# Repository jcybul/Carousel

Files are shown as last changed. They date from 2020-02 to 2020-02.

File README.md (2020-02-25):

# Carousel

The Carousel Irrigation System at the Southern Arava R&D is an agricultural research system used to measure the effects of different water salinities on plants.

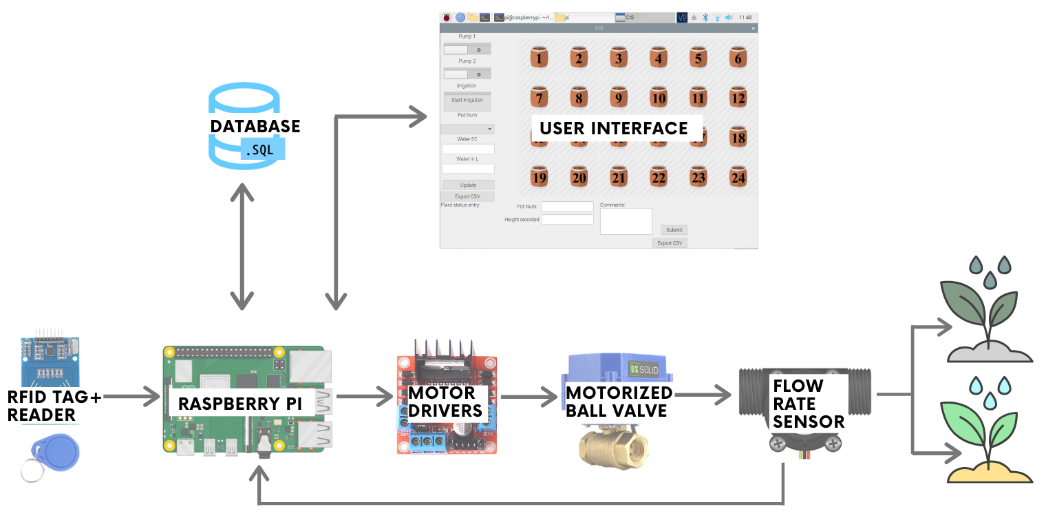
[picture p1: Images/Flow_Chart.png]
Flow chart


The system is divided into three main components:
   1. Hardware 
   2. Database 
   3. User-interface 
   
# HARDWARE

This project is meant to create a supplementary automatic irrigation system to the existing carousel, using the spinning capabilities it already has. For this project we will be using a Raspberry Pi 4 with Raspbian as the operating system. The hardware components required are the following: 

   1 Raspberry pi 4 (https://www.raspberrypi.org/products/raspberry-pi-4-model-b/)
   2  Electronic ball valves (https://www.amazon.com/gp/product/B06XRJF4JG/ref=ppx_yo_dt_b_search_asin_title?ie=UTF8&psc=1)
   2 Flow rate sensors (https://www.amazon.com/gp/product/B00VKAT9VA/ref=ppx_yo_dt_b_search_asin_title?ie=UTF8&psc=1)
   1 L298N motor driver (https://cdn.instructables.com/ORIG/FCN/YABW/IHNTEND4/FCNYABWIHNTEND4.pdf)
   1 RFID scanner (https://www.amazon.com/gp/product/B076HSDF2Y/ref=ppx_yo_dt_b_search_asin_title?ie=UTF8&psc=1)
   24 RFID tags (https://www.amazon.com/gp/product/B076HSDF2Y/ref=ppx_yo_dt_b_search_asin_title?ie=UTF8&psc=1)

Aside from that, a soldering board extension and a soldering iron is recommended for organization

The wiring of the system can be seen in the pictures below:

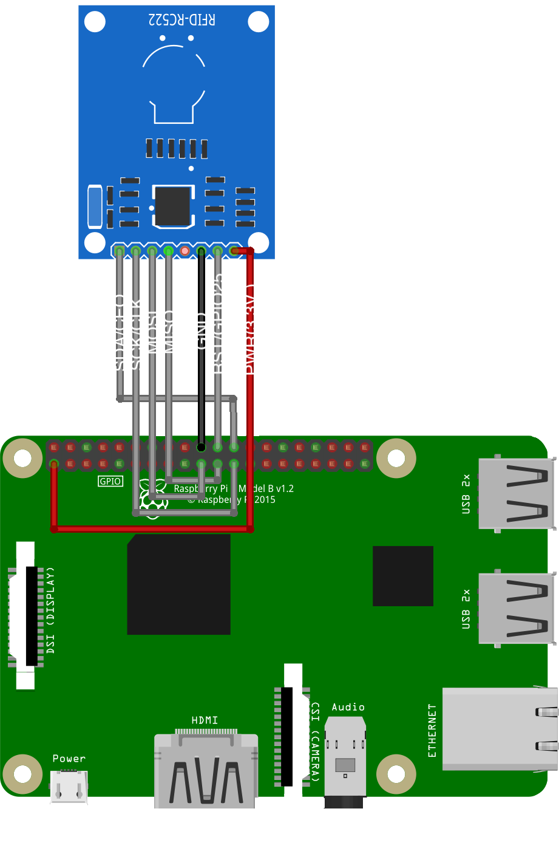
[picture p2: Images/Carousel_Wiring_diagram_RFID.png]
Wiring Diagram of the RFID scanner

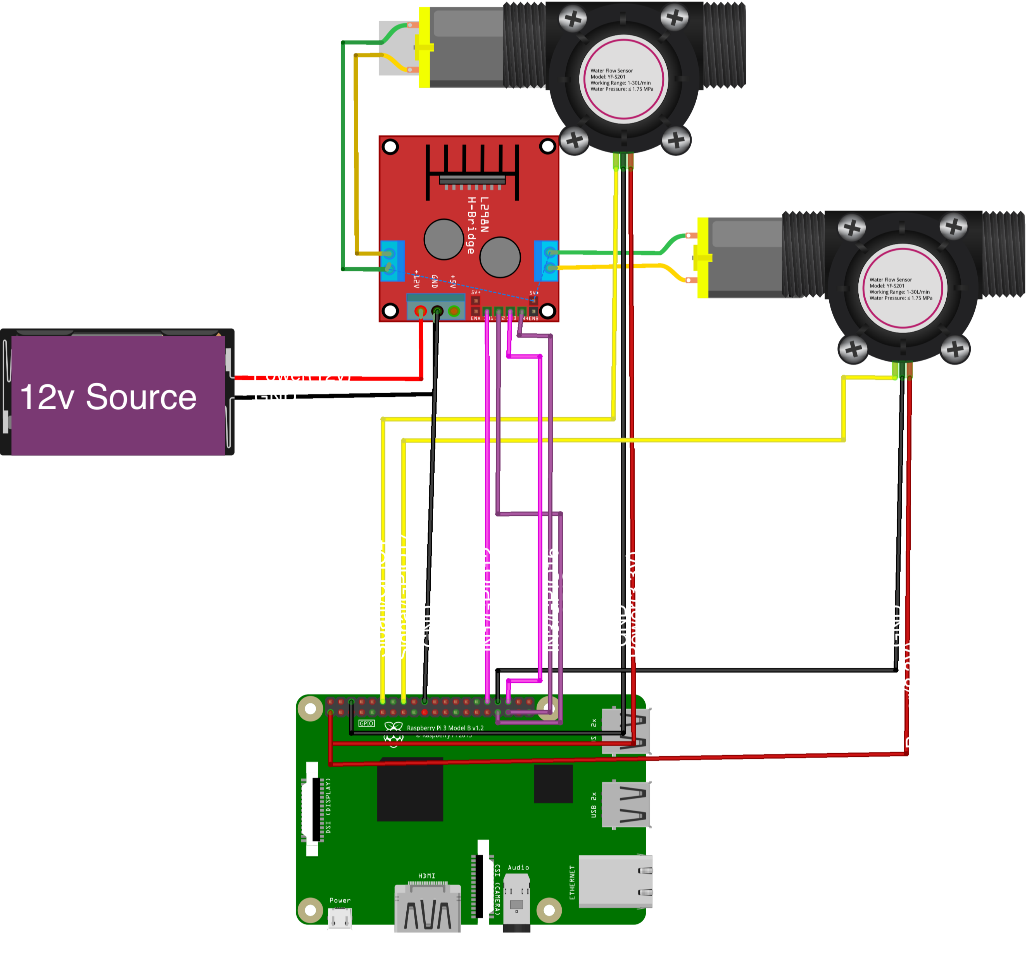
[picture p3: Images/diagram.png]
Wiring Diagram of the Flowrate sensors and ball valves
 

[Refer to the fritzing files for more detailed information]( /Fritzing_Files)

# DATABASE

The database used for this project is a MySql database running locally on the Raspberry Pi, which makes access to it very simple, this database is only running when the Raspberry Pi is turned on.

# USER-INTERFACE

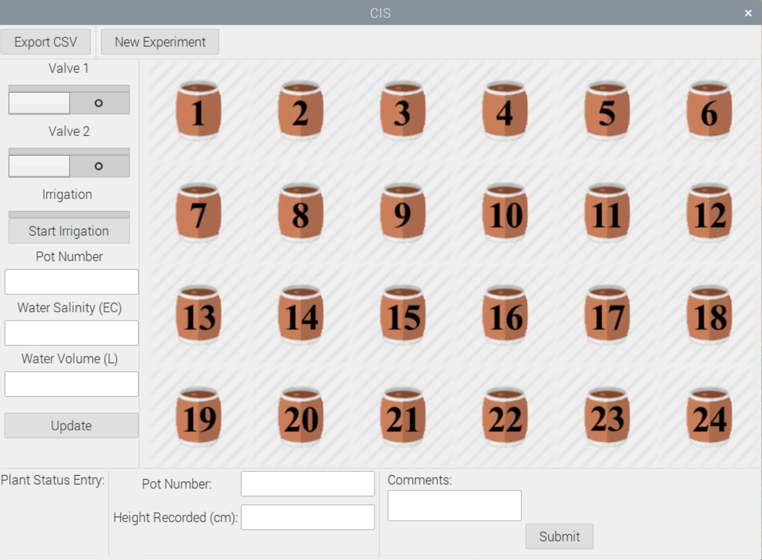
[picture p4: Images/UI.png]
 

The user-interface was created using python, the GTK library, which is a free and open-source cross-platform widget toolkit for creating graphical user interfaces, and Glade for the design.

# USER-MANUAL

A user manual was created for operating the system
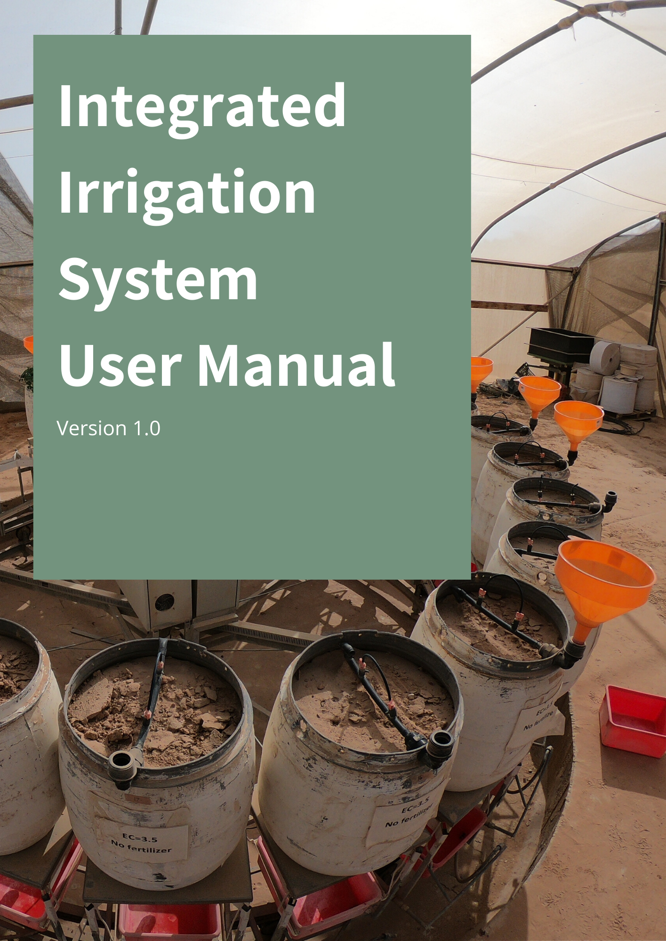
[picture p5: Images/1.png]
 
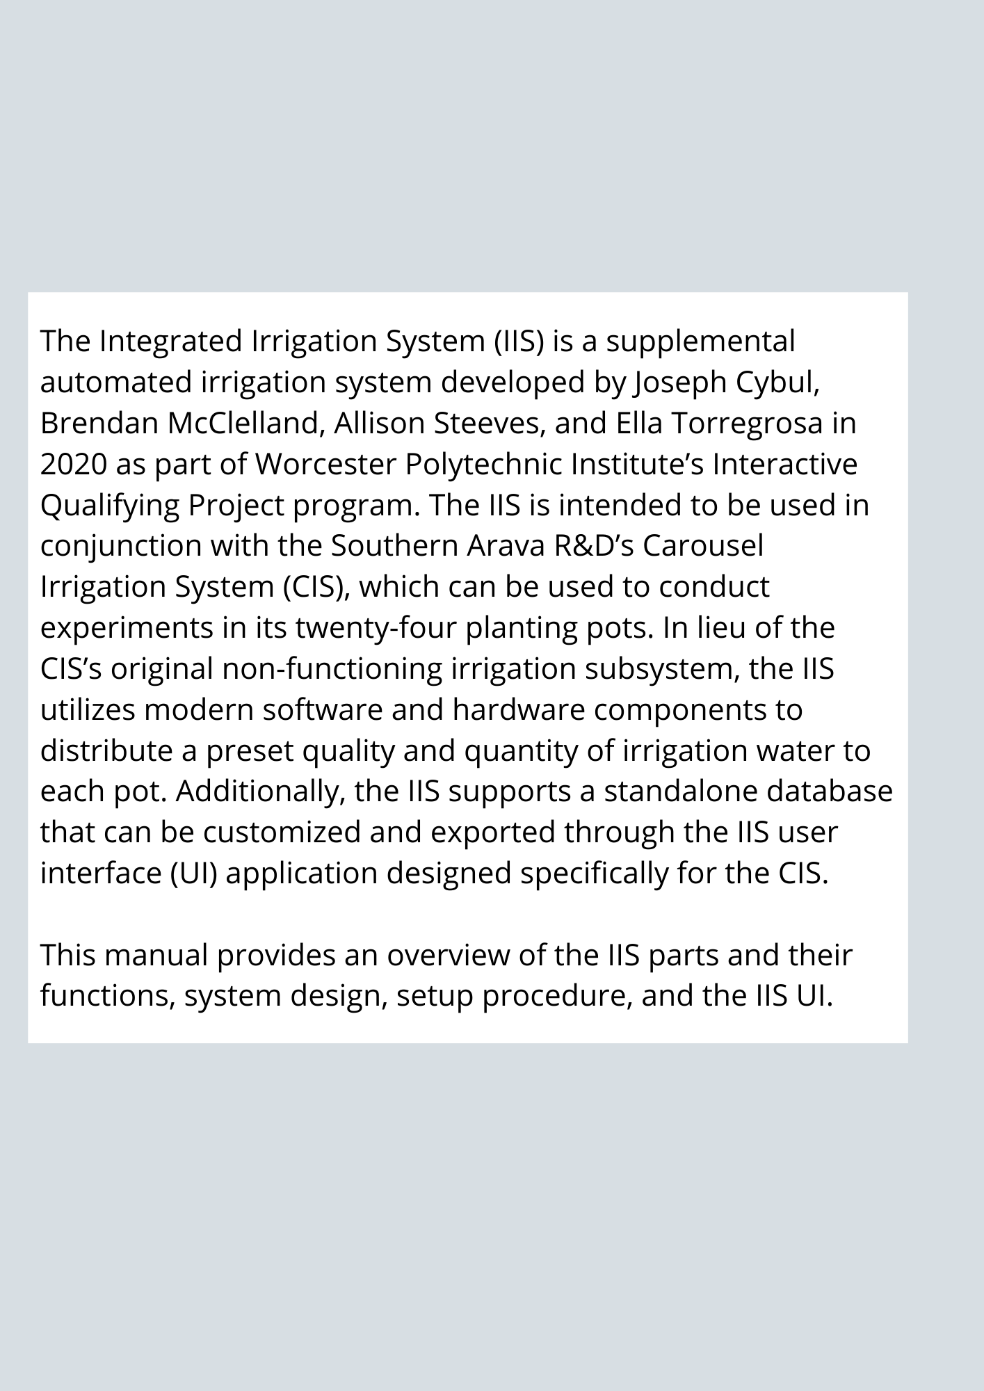
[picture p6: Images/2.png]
 
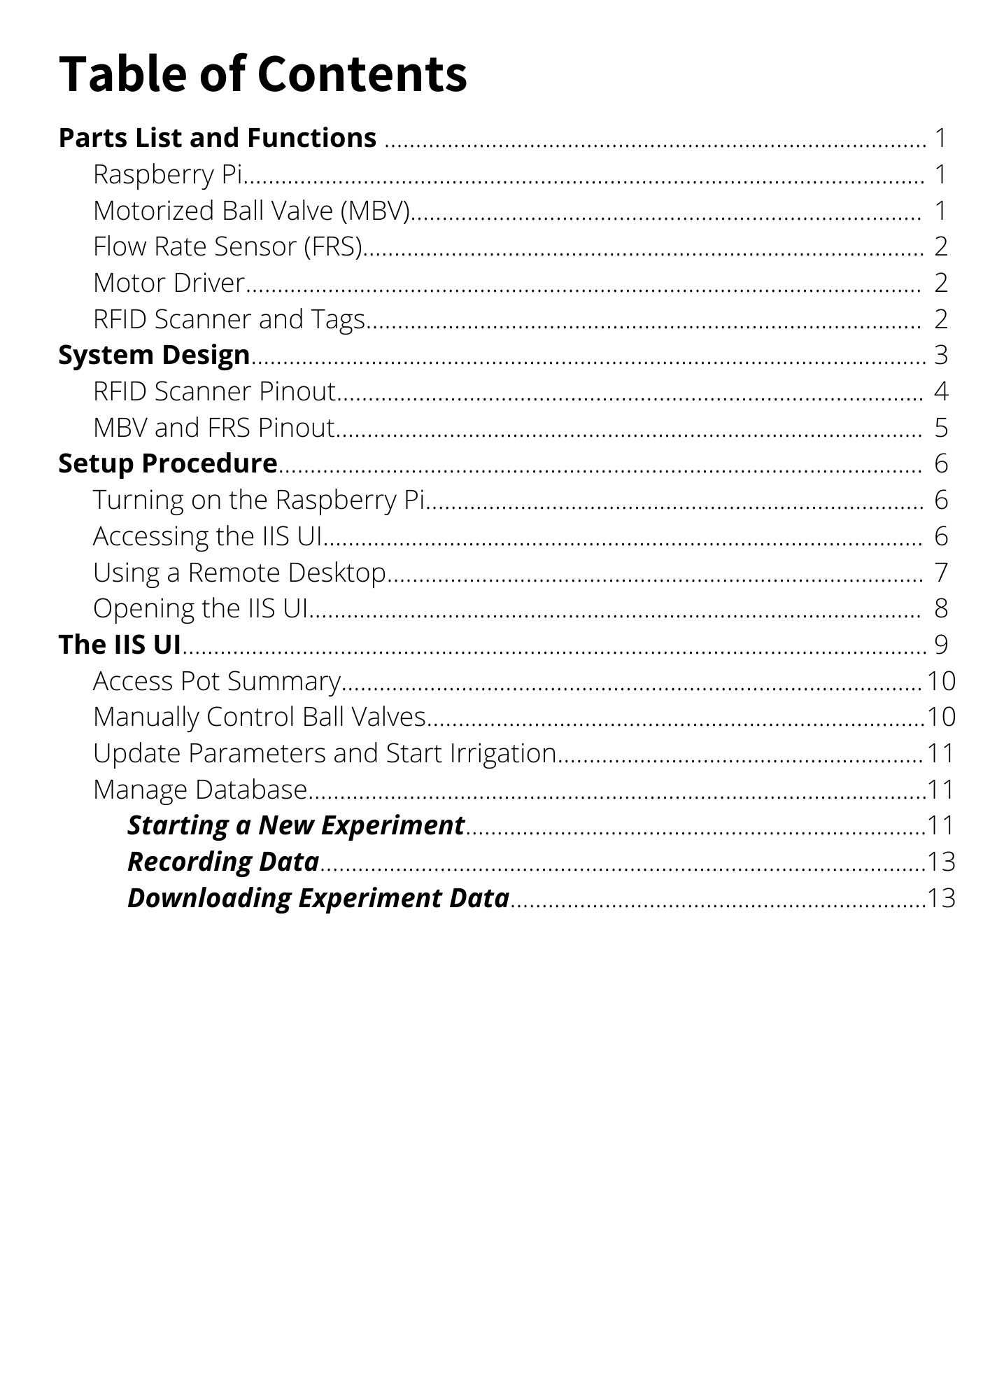
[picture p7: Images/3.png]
 
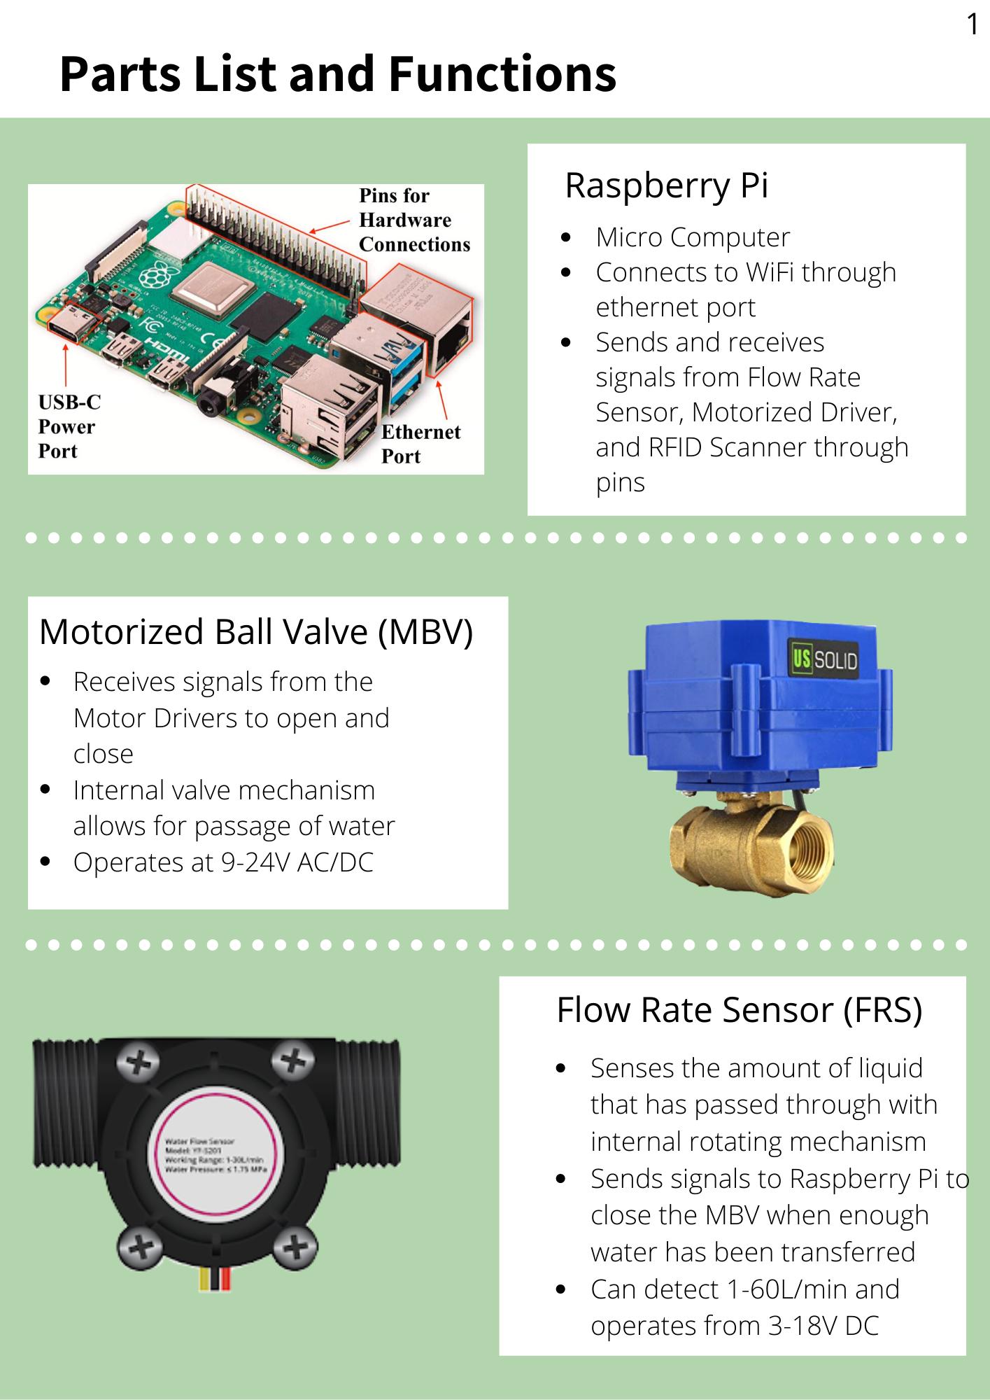
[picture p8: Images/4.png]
 
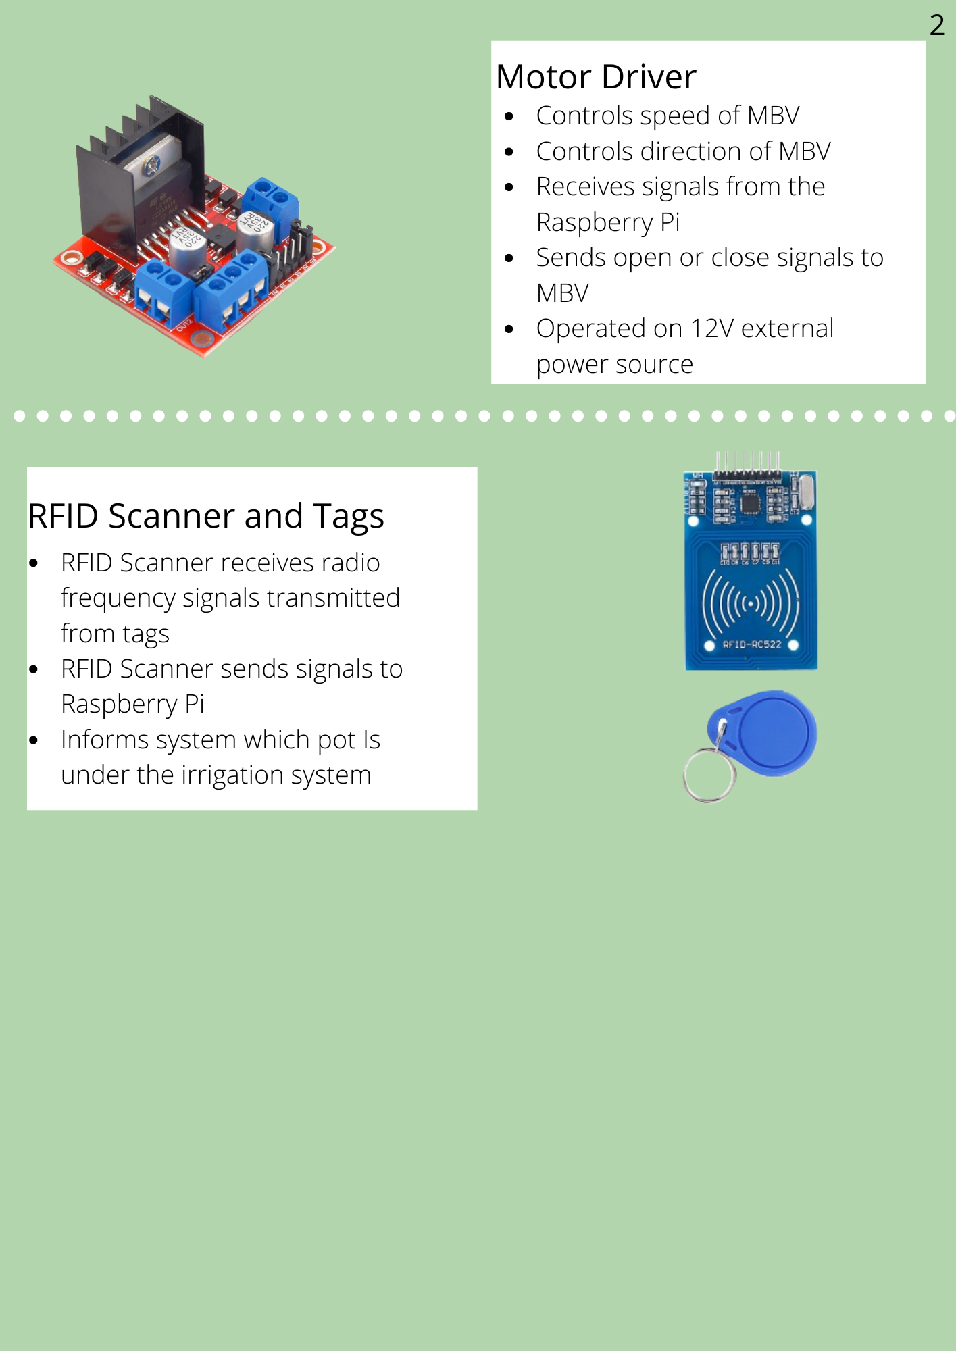
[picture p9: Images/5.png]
 
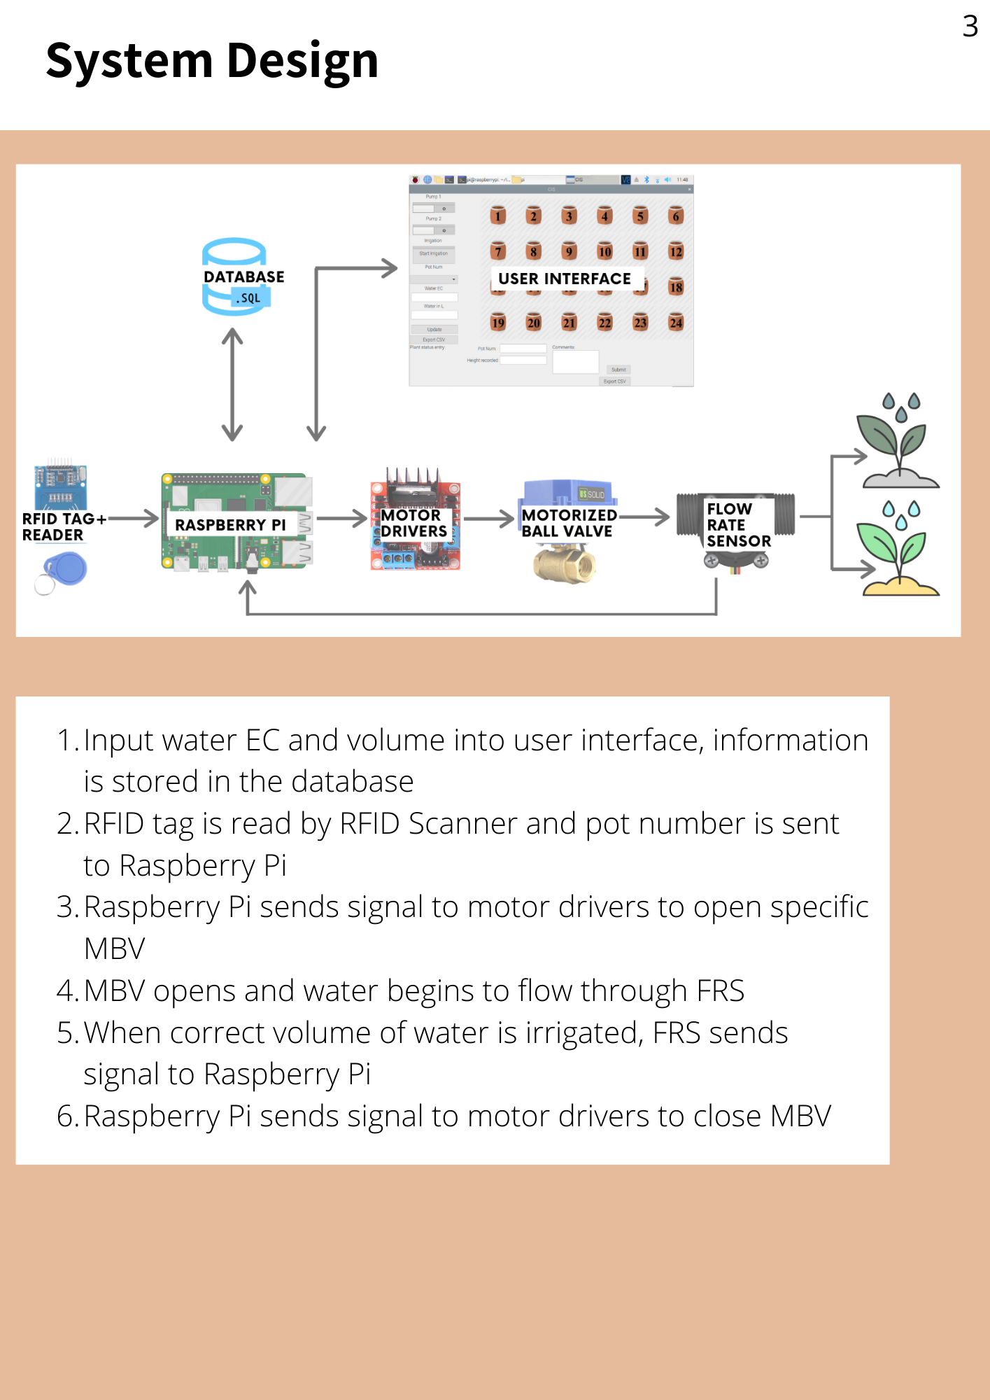
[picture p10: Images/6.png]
 
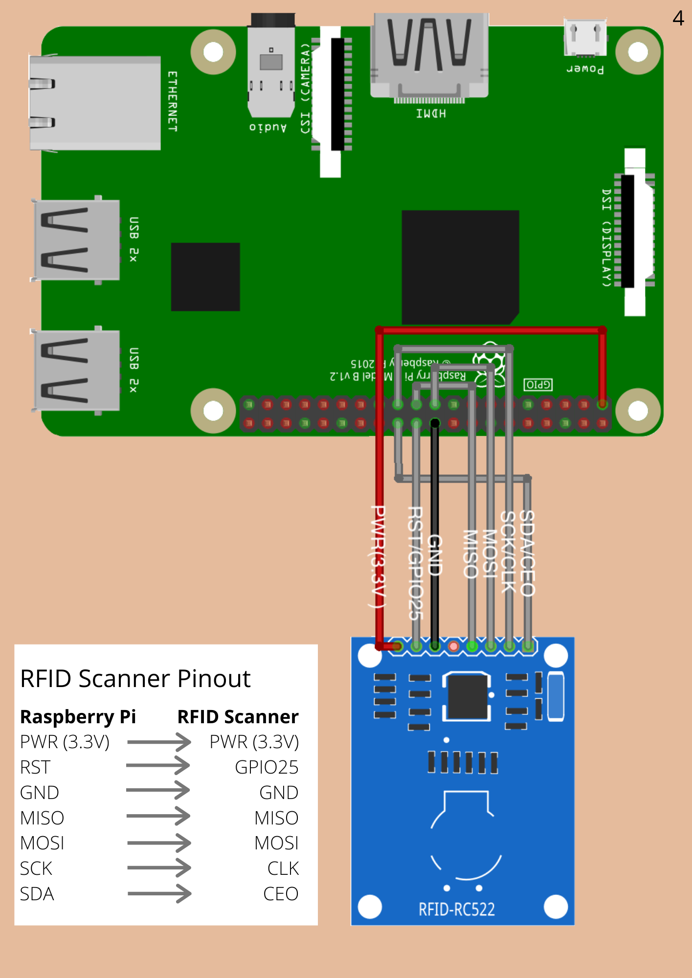
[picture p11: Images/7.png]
 
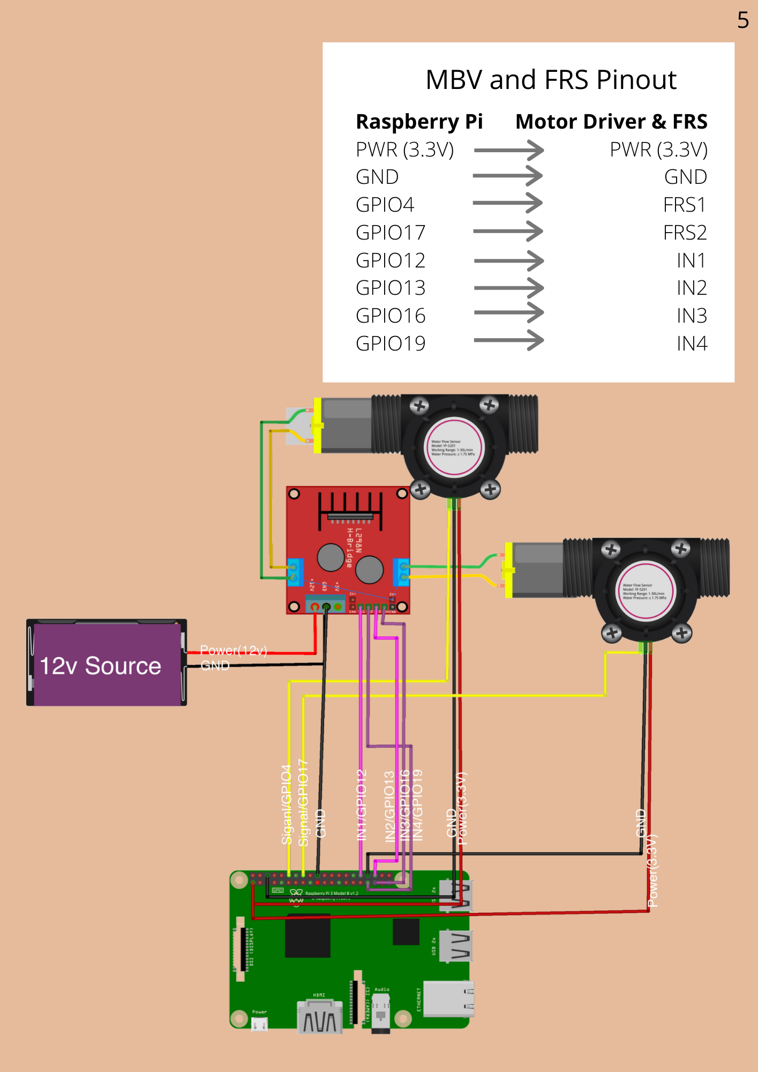
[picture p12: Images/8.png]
 
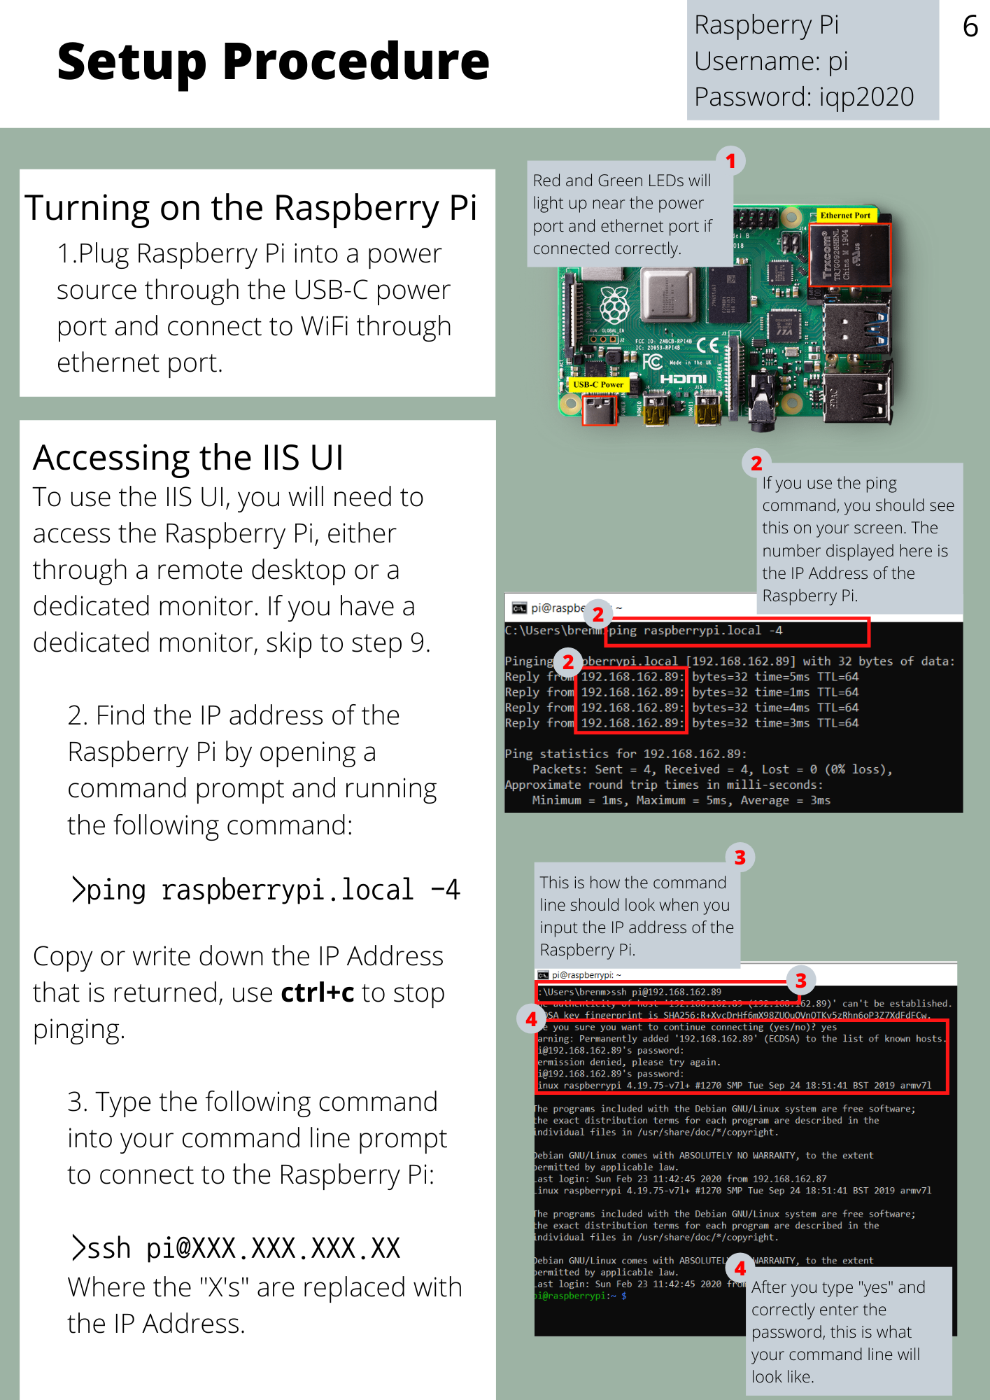
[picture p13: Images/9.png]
 
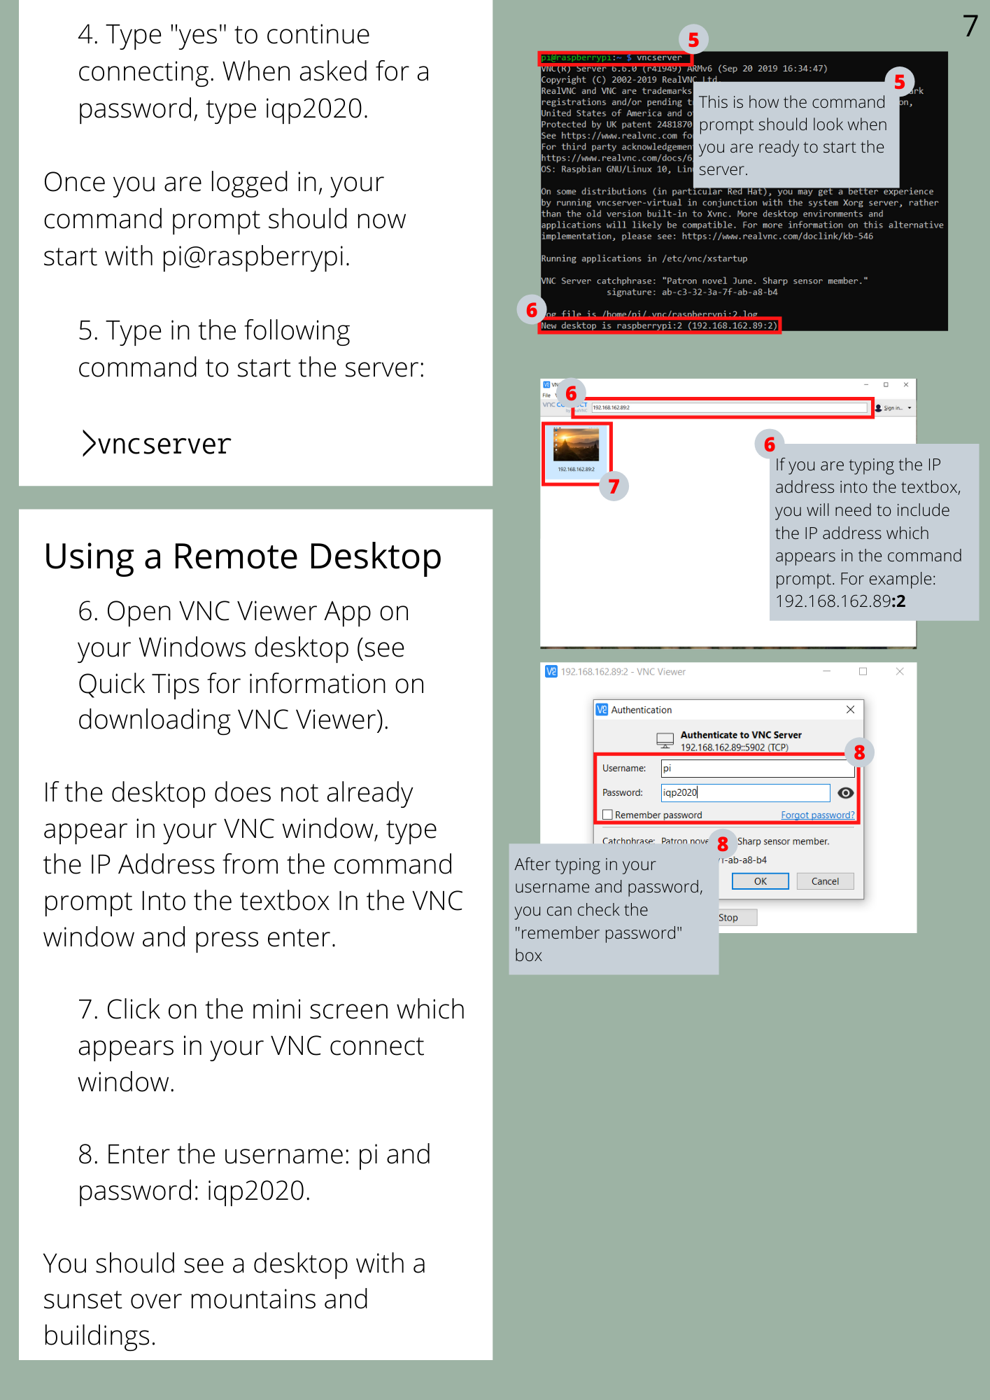
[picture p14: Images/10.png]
 
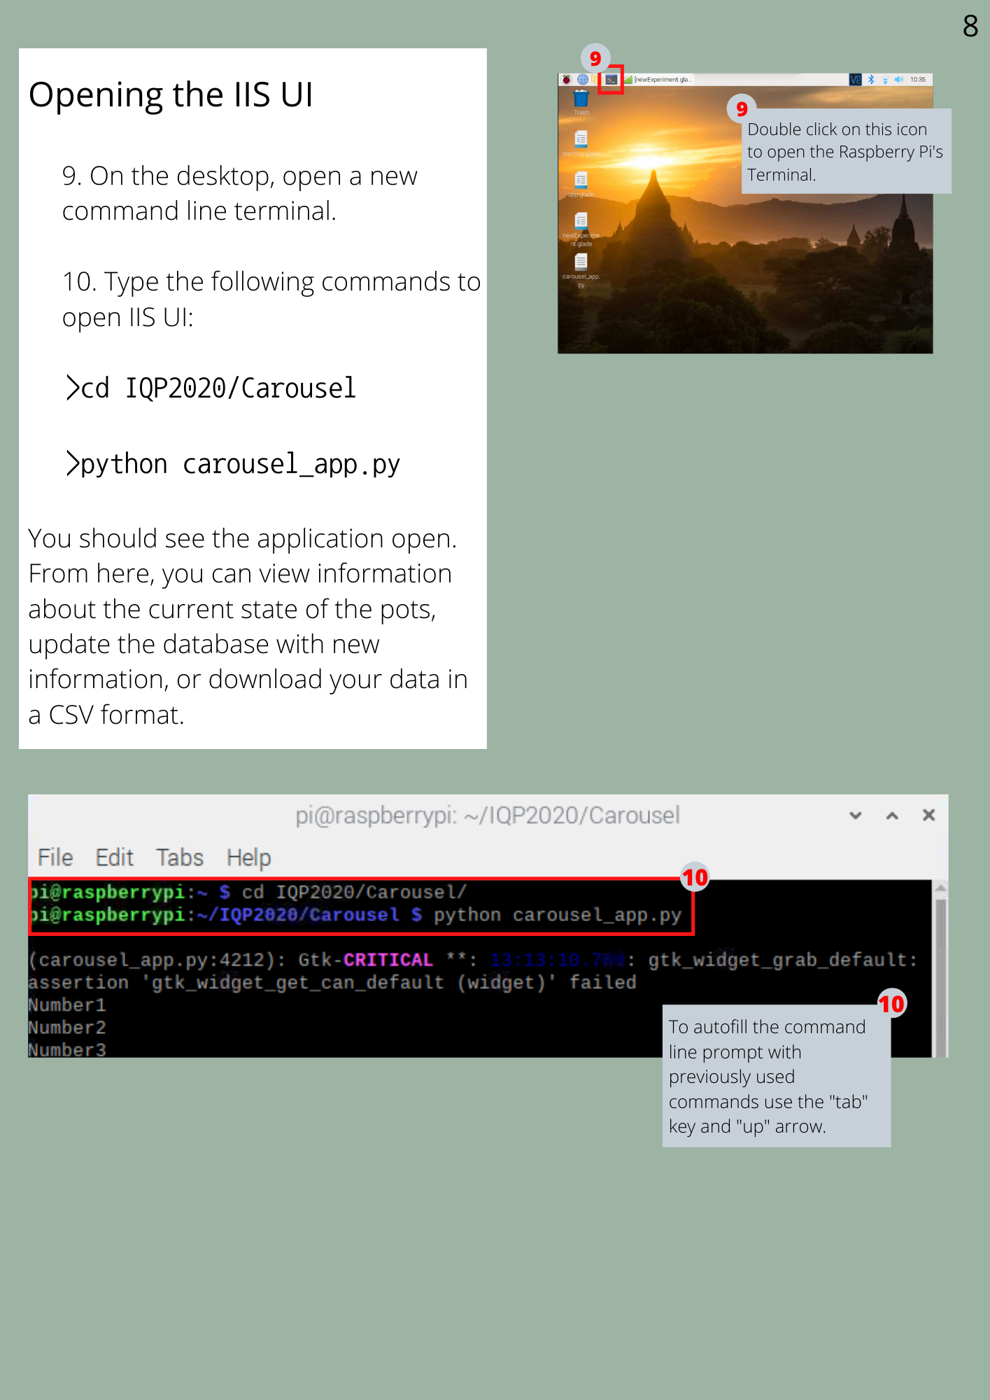
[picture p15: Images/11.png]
 
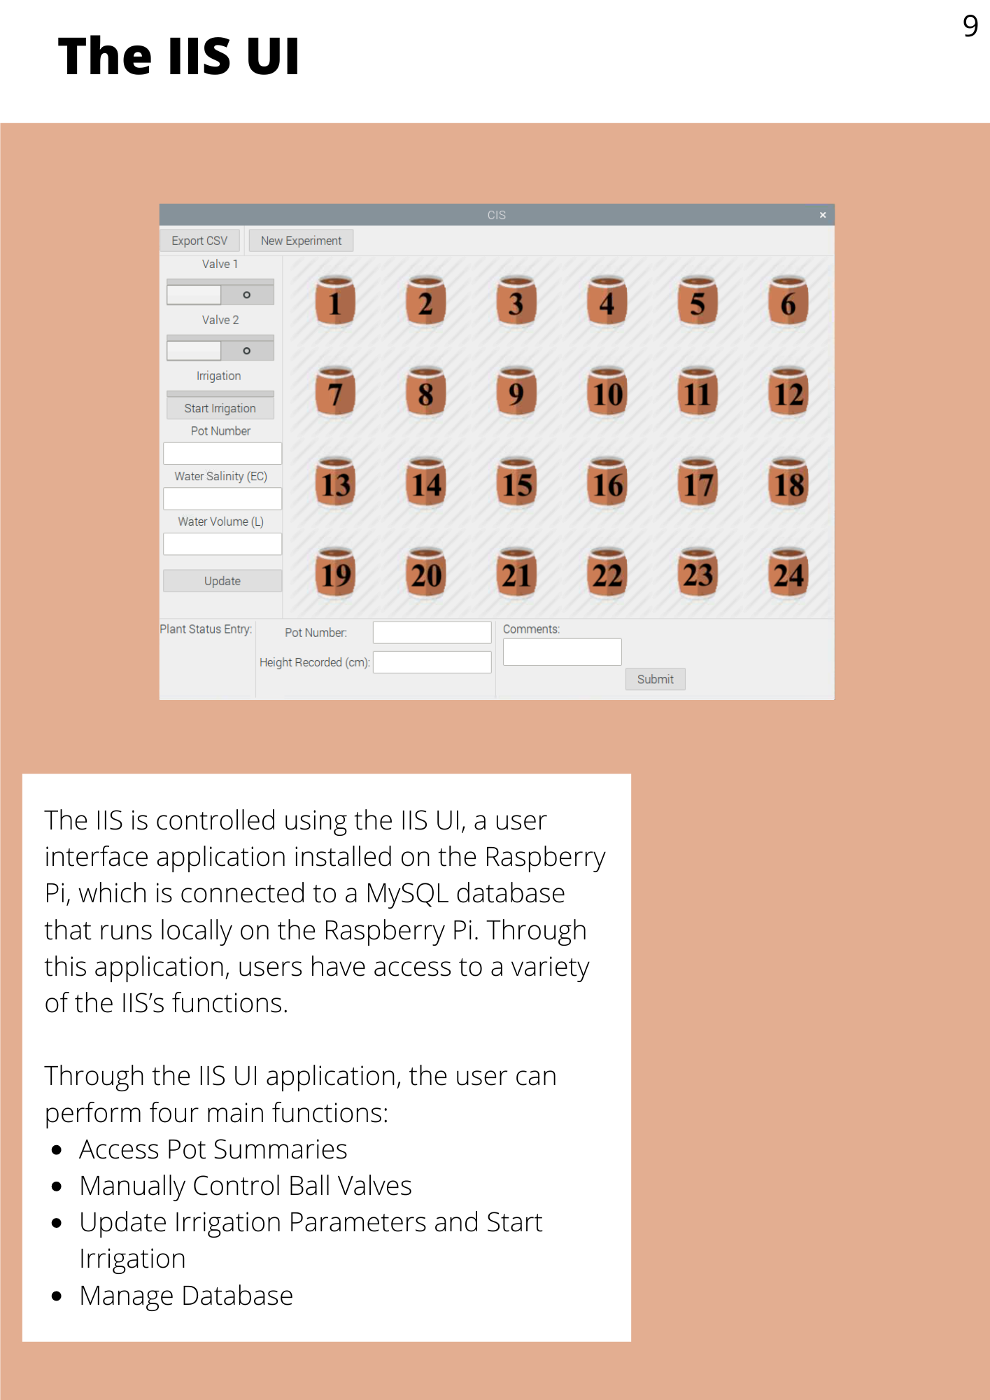
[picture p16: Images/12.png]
 
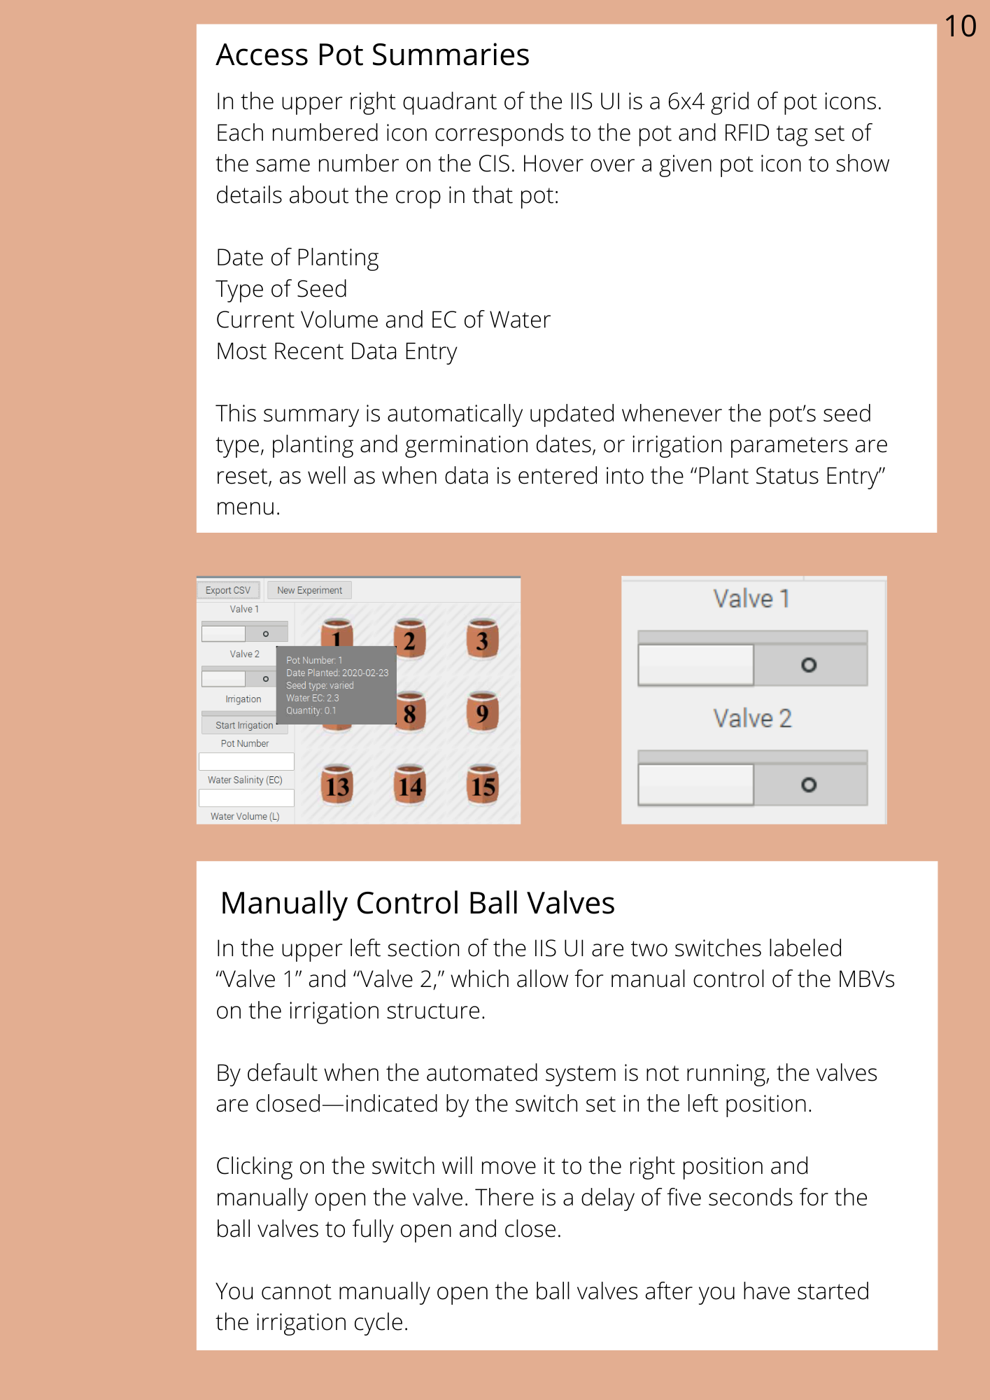
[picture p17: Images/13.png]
 
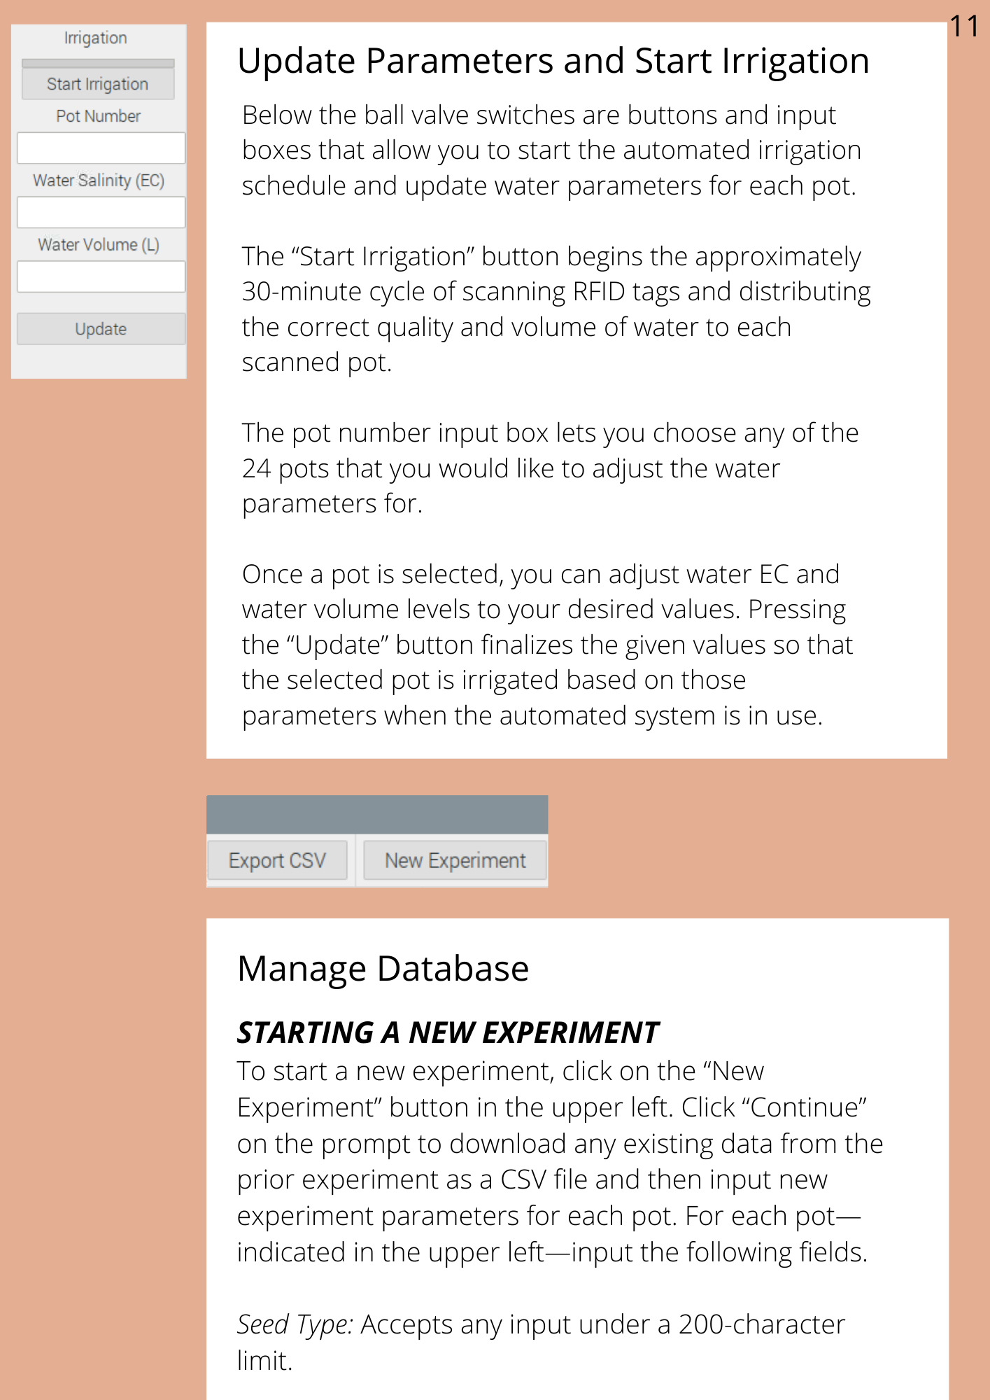
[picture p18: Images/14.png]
 
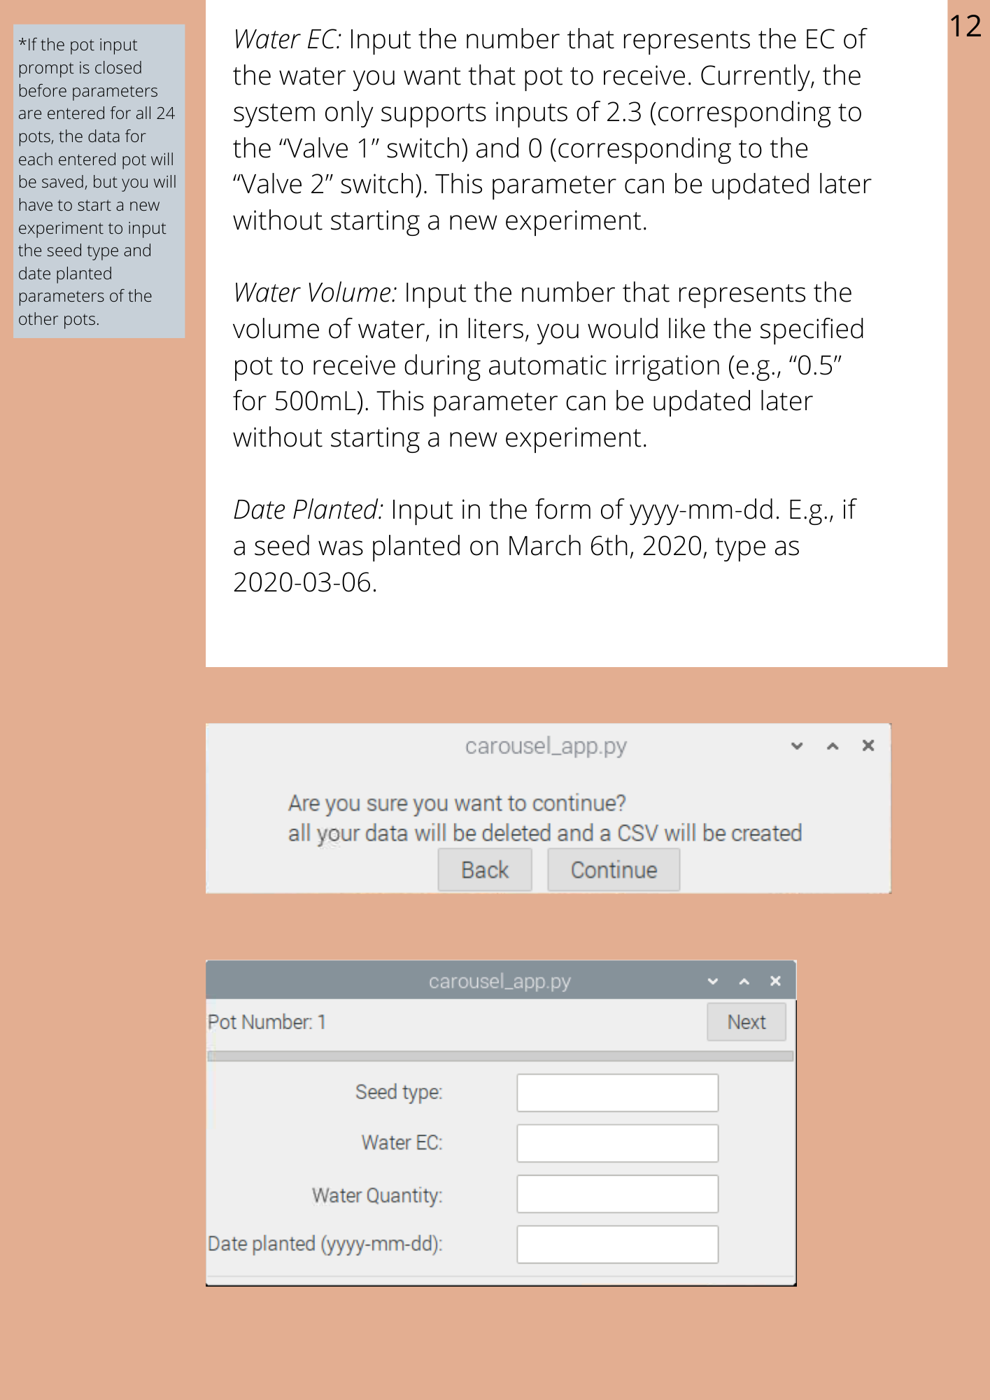
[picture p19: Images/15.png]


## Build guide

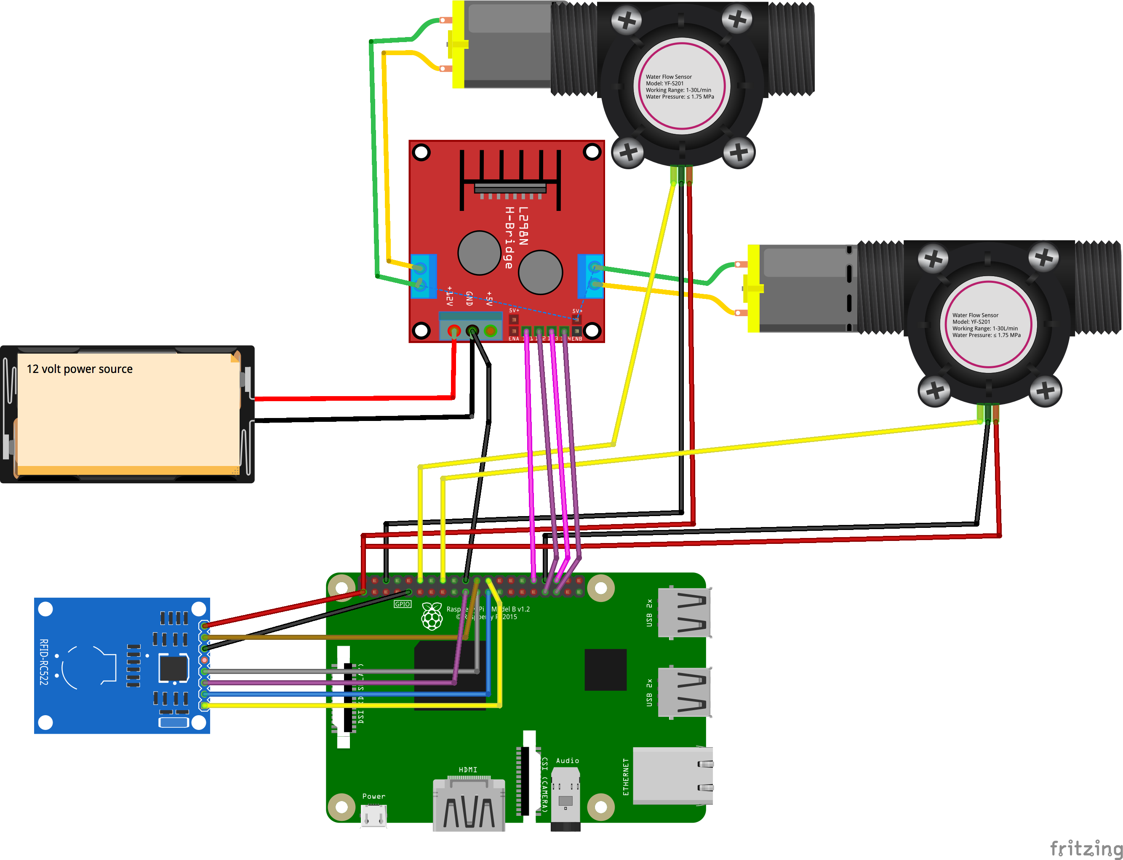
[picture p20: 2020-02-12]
Images/Carousel_Wiring_diagram_bb.png

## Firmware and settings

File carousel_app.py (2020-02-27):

import gi
import sys
from gi.repository import GObject
gi.require_version('Gtk', '3.0')
from gi.repository import Gtk
import RPi.GPIO as GPIO
import time
import MySQLdb
from time import sleep
import time    
import csv
import datetime
from threading import Thread
from multiprocessing import Process
from mfrc522 import SimpleMFRC522

in1 = 12
in2 = 13
in3 = 16
in4 = 19
def GPIOsetup():
    GPIO.setmode(GPIO.BCM)
    GPIO.setup(in1,GPIO.OUT)
    GPIO.setup(in2,GPIO.OUT)
    GPIO.setup(in3,GPIO.OUT)
    GPIO.setup(in4,GPIO.OUT)
    GPIO.setup(4,GPIO.IN,pull_up_down = GPIO.PUD_UP)
    GPIO.setup(17,GPIO.IN,pull_up_down = GPIO.PUD_UP)
    GPIO.add_event_detect(4,GPIO.FALLING, callback = countPulse2)
    GPIO.add_event_detect(17,GPIO.FALLING, callback = countPulse)


global count
count = 0

global count2
count2 = 0

newExperiment = 1


def setLabel(number):
    Npot_number.set_text(str(number))

def doneLabel():
    done.set_text("Done, click next to continue")



def countPulse(channel):
    global count
    count= count+1

def countPulse2(channel):
    global count2
    count2= count2+1


GPIOsetup()
def irrigate():
   # print("in irrigation")
       pot_count = 0
       
   # print ("reading")
   # while(pot_count < 2):
       
       while(pot_count < 24):
        GPIO.cleanup()  
        reader = SimpleMFRC522()  
        print("the Pot_count is: " + str(pot_count))
        global count,count2  
        try:
            print(" Waiting to read ")
            id,rfid = reader.read()
            print(rfid)
        finally:
            print("cleaned")
            GPIO.cleanup()
        time.sleep(1)
        try:
            if(int(rfid) > 0 and int(rfid) < 25):
                pot_count = pot_count+1
                GPIOsetup()
                print ("Read pot: " + rfid)
                try:
                    w = int(rfid)
                except ValueError:
                    print("not transformable int")
                print("coneverted")
                if(w != 2):
                    water = ((w -2) + 24 ) % 24
                else:
                    water = 4
                print ( "Water pot number  " + str(water))
                time.sleep(5)
                db = MySQLdb.connect(host="localhost",    # your host, usually localhost
                             user="root",         # your username
                             passwd="iqp2020",  # your password
                             db="mydb")    
                cur = db.cursor(MySQLdb.cursors.DictCursor)
                try:
                    query = "SELECT * from Carousel where barrel_num = %s"
                    cur.execute(query,[str(water)])
                    result = cur.fetchall()
                    for r in result:
                        q = (r['Water_Liters'])
                        ec = (r['Water_ec'])
                        print("The amount is "+ str(q) + " and the ec " + str(ec))
                finally:
                    db.close()
                print("ready to water")
                count = 0
                count2 = 0
                if(ec == 2.3):
                    print(str(water) + " ec 2.3")
                    while(count/(60 *7.5) < q):
                         print(count/(60 *7.5))
                         irrigate_open(ec)
                    #time.sleep(3)
                    print("calling the close function")
                    irrigate_close(ec)
                elif ( ec == 0.0):
                    while(count2/(60 *7.5) < q):
                        print(count2/(60*7.5))
                        irrigate_open(ec)
                    print( "calling the close function")
                    irrigate_close(ec)      
        except ValueError:
            print(" Not a number ")
 
                 

def irrigate_open(ec):
    print( "opening the water")
    if(ec == 2.3):
        GPIO.output(in1,GPIO.HIGH)
        GPIO.output(in2,GPIO.LOW)
        print("opened")
    elif(ec == 0):

        GPIO.output(in3,GPIO.HIGH)
        GPIO.output(in4,GPIO.LOW)


def irrigate_close(ec):
    print( "closing the water")
    GPIO.output(in1,GPIO.LOW)
    GPIO.output(in2,GPIO.HIGH)
    time.sleep(5)
    print("closed")
   


def setToolTip():
    db = MySQLdb.connect(host="localhost",    # your host, usually localhost
                     user="root",         # your username
                     passwd="iqp2020",  # your password
                     db="mydb")    
    cur = db.cursor(MySQLdb.cursors.DictCursor)
    cur2 = db.cursor(MySQLdb.cursors.DictCursor)
    for x in range (1, 25):
        query2 = "Select Height,date_recorded from Plant_records where barrel_num = %s and date_recorded = (SELECT MAX(date_recorded) from Plant_records where barrel_num = %s group by barrel_num)"
        query = "SELECT *  from Carousel WHERE Barrel_num = %s"
        cur.execute(query,[str(x)])
        cur2.execute(query2,([str(x)],[str(x)]))
        result2 = cur2.fetchall()
        result = cur.fetchall()
        sstring = "pot_" +str(x)
        s =""
        temp = builder.get_object(sstring)
        for t in result:
            print("Number"+ str(t['Barrel_num']))
            s = " Pot Number: " + str(t['Barrel_num']) +" \n Date Planted: " + str(t['Date_planted'])+"\n Seed Type: " + str(t['Seed_type']) +" \n Water EC: " + str(t['Water_ec']) +" \n Quantity: " + str(t['Water_Liters'])
        for f in result2:
            s =  s + "\n Recorded Height(cm): "+ str(f['Height'])  + "\n Height Recorded on: " + str(f['date_recorded'])
        temp.set_tooltip_text(s)

def exportCsv2():
        fileName = 'CSV/Carousel' +  time.strftime('%Y-%m-%d %H-%M-%S')
        db = MySQLdb.connect(host="localhost",    # your host, usually localhost
                     user="root",         # your username
                     passwd="iqp2020",  # your password
                     db="mydb")    
        cur = db.cursor()
        with open(fileName + '.csv','a') as Carousel:
            title_writer = csv.writer(Carousel, delimiter = ',', quotechar = '"' , quoting = csv.QUOTE_MINIMAL)
            title_writer.writerow(["Pot_num","Date_Recorded","Height","Comments","Datee_planted","Water_ec","Seed_Type","Water_Liters"])
        query = "Select Plant_records.barrel_num, date_recorded, Height, Comments, Date_planted, Water_ec, Seed_type, Water_Liters from Plant_records join Carousel C on Plant_records.barrel_num = C.Barrel_num "
        try:
            cur.execute(query)
            result = cur.fetchall()

            for r in result:
                print(r)
                with open(fileName +'.csv', 'a') as Carousel:
                    employee_writer = csv.writer(Carousel, delimiter=',', quotechar='"', quoting=csv.QUOTE_MINIMAL)
                    employee_writer.writerow([r[0],r[1],r[2],r[3],r[4],r[5],r[6],r[7]])
        finally:
            cur.close
            db.close
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

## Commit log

2020-01-22 ball valve test, and UI switch linked
2020-02-02 pump work
2020-02-02 fixed valves
